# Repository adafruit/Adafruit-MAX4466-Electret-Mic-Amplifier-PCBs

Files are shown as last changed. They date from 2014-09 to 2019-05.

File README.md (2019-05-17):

# Adafruit MAX4466 Electret Mic Amplifier PCBs
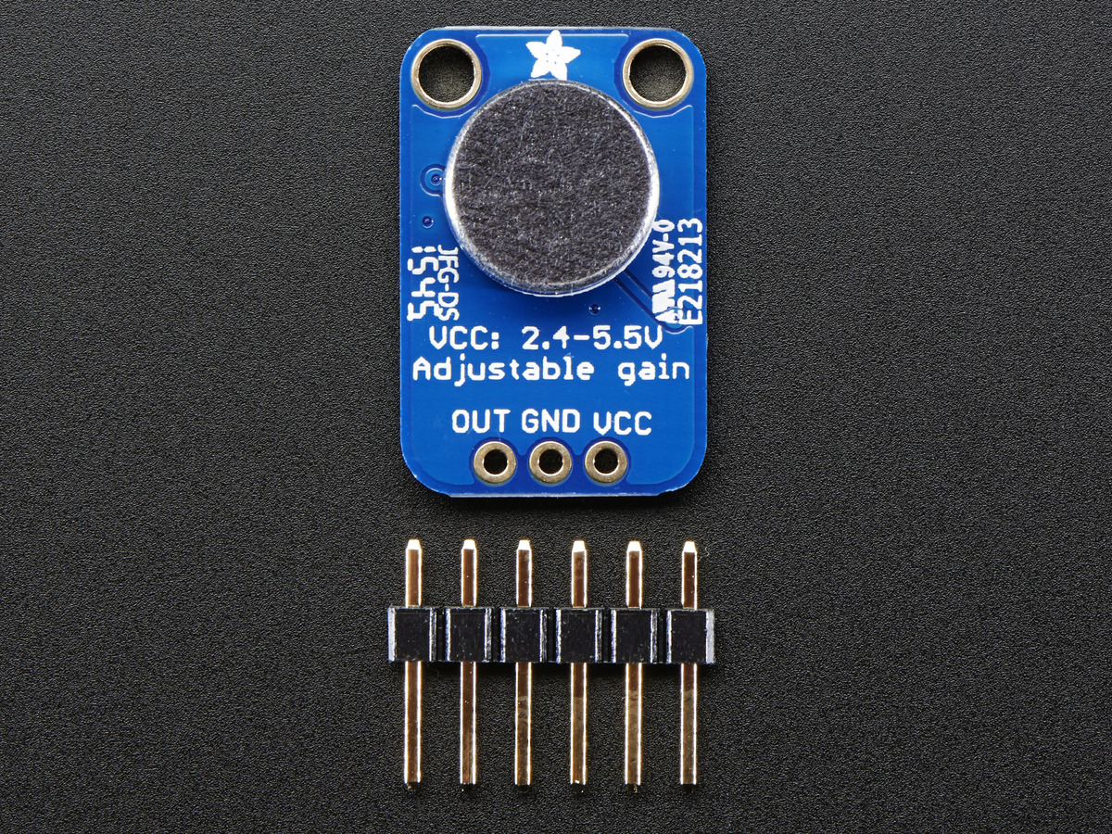
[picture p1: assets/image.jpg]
<a href="http://www.adafruit.com/products/1063"><br/>
Click here to purchase one from the Adafruit shop</a>

Add an ear to your project with this well-designed electret microphone amplifier. This fully assembled and tested board comes with a 20-20KHz electret microphone soldered on. For the amplification, we use the Maxim MAX4466, an op-amp specifically designed for this delicate task! The amplifier has excellent power supply noise rejection, so this amplifier sounds really good and isn't nearly as noisy or scratchy as other mic amp breakouts we've tried!

This breakout is best used for projects such as voice changers, audio recording/sampling, and audio-reactive projects that use FFT. On the back, we include a small trimmer pot to adjust the gain. You can set the gain from 25x to 125x. That's down to be about 200mVpp (for normal speaking volume about 6" away) which is good for attaching to something that expects 'line level' input without clipping, or up to about 1Vpp, ideal for reading from a microcontroller ADC. The output is rail-to-rail so if the sounds gets loud, the output can go up to 5Vpp!

PCB files for Adafruit MAX4466 Electret Mic Amplifier. The format is EagleCAD schematic and board layout

For more details, check out the product page at https://www.adafruit.com/products/1063

### License

Adafruit invests time and resources providing this open source design, please support Adafruit and open-source hardware by purchasing products from [Adafruit](https://www.adafruit.com)!

All text above must be included in any redistribution

Designed by Limor Fried/Ladyada for Adafruit Industries.
Creative Commons Attribution/Share-Alike, all text above must be included in any redistribution. 
See license.txt for additional information.

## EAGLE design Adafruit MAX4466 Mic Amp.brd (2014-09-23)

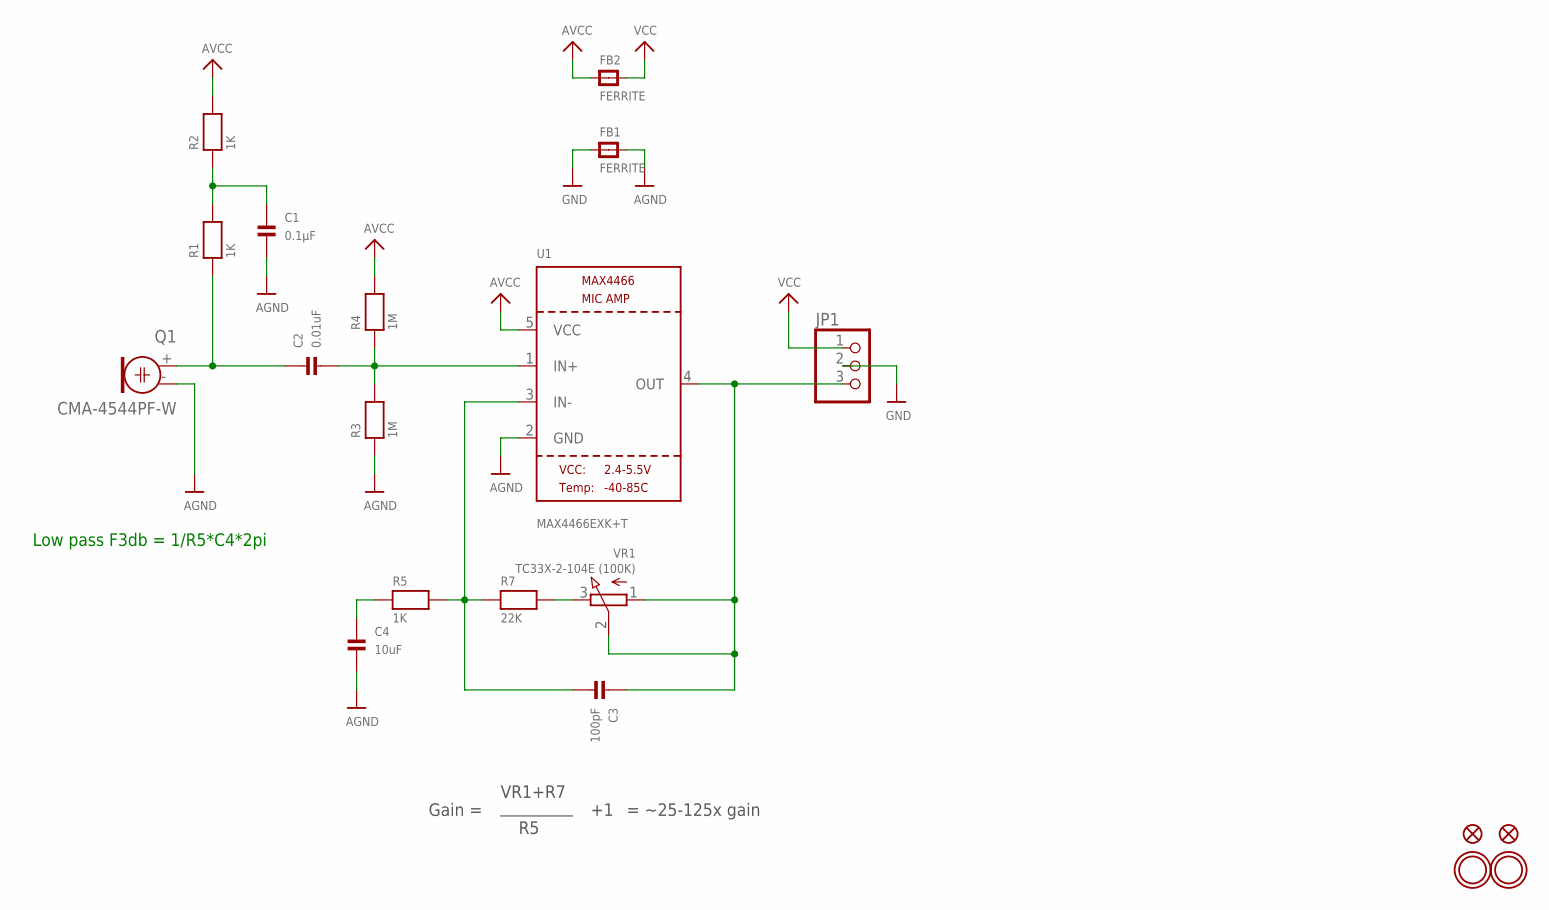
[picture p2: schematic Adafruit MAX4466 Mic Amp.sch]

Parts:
C1: 0.1µF; 0805
C2: 0.01uF; 0805
C3: 100pF; 0805
C4: 10uF; 0805
FB1, FB2: FERRITE; 0805
FID1, FID2: FIDUCIAL""; FIDUCIAL_1MM
JP1: HEADER-1X376MIL; 1X03_ROUND_76
Q1: CMA-4544PF-W; ELECTRET_9.7
R1, R2, R5: 1K; 0805
R3, R4: 1M; 0805
R7: 22K; 0805
U1: MAX4466EXK+T; SC70-5
U$11, U$14: MOUNTINGHOLE2.5; MOUNTINGHOLE_2.5_PLATED
VR1: TC33X-2-104E (100K); TRIMPOT_BOURNS_TC33X-2

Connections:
AGND: C1.2, C4.2, FB1.2, Q1.- (1), R3.1, U1.2 (GND)
AVCC: FB2.1, R2.2, R4.2, U1.5 (VCC)
GND: FB1.1, JP1.2
unnamed: C3.2, R5.2, R7.1, U1.3 (IN-)
unnamed: R7.2, VR1.3 (E)
unnamed: C2.1, Q1.+ (2), R1.1
unnamed: C1.1, R1.2, R2.1
unnamed: C2.2, R3.2, R4.1, U1.1 (IN+)
unnamed: C3.1, JP1.3, U1.4 (OUT), VR1.1 (A), VR1.2 (S)
unnamed: C4.1, R5.1
VCC: FB2.2, JP1.1

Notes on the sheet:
Gain =
VR1+R7
= ~25-125x gain
Low pass F3db = 1/R5*C4*2pi

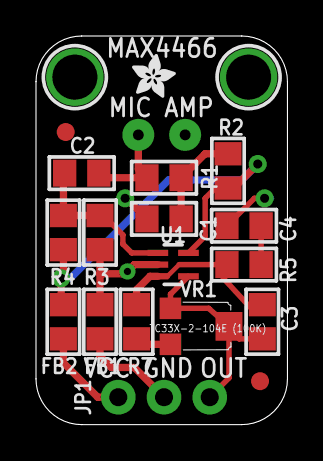
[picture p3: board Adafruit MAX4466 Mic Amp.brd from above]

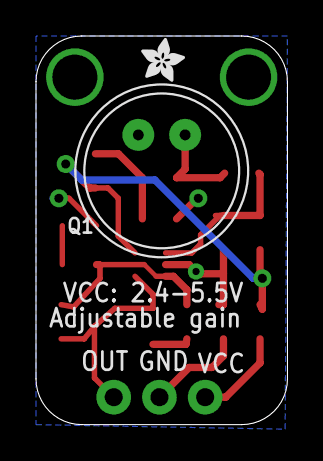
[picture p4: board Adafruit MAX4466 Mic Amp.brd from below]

Board: 2 copper layers, 14.0 x 21.6 mm, 22 parts (2 on the bottom side), 11 nets.

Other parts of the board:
U$16, U$17: ADAFRUIT_2.5MM

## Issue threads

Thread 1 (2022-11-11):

Dimensions of board in an easy readable format

berrak, 2022-11-11:
Hi,
I can not find this board's size (width x length) in a quickly standard readable format, like a pdf file.
There is no information about this on the product page either. You can't seriously require to bother with the installation Eagle just for such basic information. Forgive me if I just missed the exact location. If, indeed, dimensions are found elsewhere, let me know.

berrak, 2022-11-11:
Simply update the README with the data, please.

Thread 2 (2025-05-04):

MAX4466 not detecting voice beyond 30cm

fadhilah137, 2025-05-04:
Hi, I'm using the MAX4466 microphone module with an ESP32 to detect voice levels. The sensor works, but it only responds to loud sounds or when someone speaks very close (less than 30cm). Normal speaking voice from more than 30cm away is not detected properly.

This project is intended to detect noise levels in a library environment, where even low voice levels need to be captured to monitor quietness. I’ve tried adjusting the onboard gain potentiometer, but it didn’t help much.

Is this a limitation of the MAX4466 itself, or could it be related to my code, power supply, or gain settings? Or does anyone know any other sensor that can be used in this project?

Any advice or suggestions would be really appreciated. Thank you!

ladyada, 2025-05-04:
did you purchase an adafruit breakout board?

fadhilah137, 2025-05-04:
> did you purchase an adafruit breakout board?

Yes, I did. please help me, I'm really confused right now

Closed 2025-05-04.

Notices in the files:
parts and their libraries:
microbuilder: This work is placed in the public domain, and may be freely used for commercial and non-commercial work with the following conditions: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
